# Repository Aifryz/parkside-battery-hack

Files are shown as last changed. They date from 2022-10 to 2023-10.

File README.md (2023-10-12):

# parkside-battery-hack
Hack which allow for the PLG 20 A1 charger to charge old style parkside 21V batteries (and possibly others)
### Status update: Battery died roughly 4 months after this change

## TLDR: Use Arduino Nano to fake the impulses sent by battery to enable the charger to work. See code for more info.
# The story
Some time ago a friend asked me if I could fix his parkside drill charger. Obviously I couldn't refuse, I love fixing stuff even when it makes little economic sense.

After taking a quick peek at the internals, it was obvious that it wouldn't be an easy job.
What I assumed were current sense/limiting resistors were completely vaporized. Main switching transistor was shorted, and I had little trust in the primary side switching ic. especially when I had no part number nor datasheet for it.
Replacement chargers were not available since it's an old design, but more modern chargers were available cheaply. We thought that maybe we could just simply replace the internals?

It doesn't look half bad, it seems like the battery is just being connected through MOSFET switch. The third pin marked as "ID" is probably used to check if the battery is inserted.
Maybe it would work if I connected the battery directly?

It didn't work. This charger have some self diagnostics which sense that the output is shorted/overloaded and disconnects the battery terminals from voltage output. In this case it was completely disabling the primary side switching IC, since the output voltage kept falling to approx 2V.

But how? Obviously we have an optocoupler. Normally this optocoupler would work with TL431 reg to regulate output voltage, but circuit in this charger was more complicated.

Obviously, I did not have a schematic available, so some reverse engineering was needed.
First thing I like to do when REing a board is to find details about the largets IC. In this case it was a LGT8P22A.
But the research resulted in only finding someone who had the same problem as I did.
Even the search on Baidu which sometimes help when researching obscure chineese ICs resulted in me finding someone who tried to find more data about this part.

# Reverse engineering
This board is a very simple single sided board, so reverse enginnering it was relatively pleasant experience.
After maybe 2 hours to mark the connections and another 2 hours to redraw the schematics I had something I could work with.

Resistors and capacitors are easy, since values are already written on them.
With some other components, i could immediately decode what they were using standard smd code books.
Others were more tricky, such as the what I guess is the main switching IC, and some SOT23 parts.
Thanks to the schematics above I assumed that the SOT23 part had to be a TL431 clone. The only way to find out if it was was to measure voltage at X terminal.
Beautiful 2.5V confirmed my suspicions. This charger is alsmost identical to standard issue TL431 powered isolated SMPS.
The only interesting thing was this weird combination of 2 resistors and  1 capacitor connected between TL431  and LGT8P22A.
It had to be an output from LGT8P22A since if we assume that the path is high impedance we can see that we cannot get the nominal 21V at the output needed to charge the battery packs.

The only way that we could get 21v at battery terminals is when this branch would be tied to GND.
So this pin has to be some kind of output. Rather large R and C looks a lot like a low pass filter. Maybe it's simple PWM DAC?

Indeed it looks like one.
So the LGT8P22A part is obviously some kind of microcontroller used both to check if valid battery is connected and to regulate the output voltage. It's also used in the battery packs.
My first thought, as a primarily software dev was to try and readout the program memory, reverse enginner this protection disable it and reprogram. That quickly fell through after roughly 27 seconds of thinking:
- I did not have pinout
- I did not have the datasheet
- I did not know the architecture
- I did not know if it was a reprogrammable part (probably not)
But maybe there's easier way in?
As I said before, the battery pack is connected by 3 terminals: "+", "-" and ID
"+" and "-" are obvious, they are directly connected to the cells but the ID pin is intersting.
From what I found while doing research on this charger I found out that the battery communicates with charger using series of impulses. Let's attack that!
But there's a problem, I don't have the battery for this charger, only the older model.
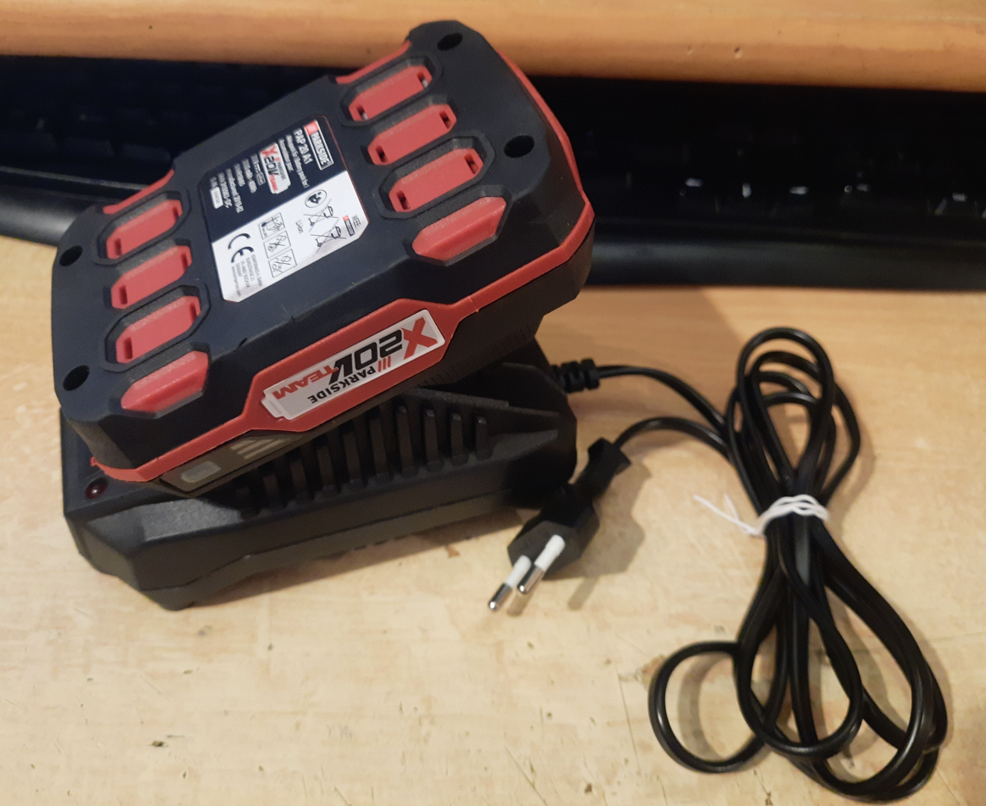
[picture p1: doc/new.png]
Image of a new charger and battery

So 120 PLN later I became an owner of a fresh battery and even fresher charger :)

After confirming that the charger internals were the same, I scoped the ID pin hoping that the protocol would be a simple. Luckily a simple repeating pulse pattern apeared.
Sadly it wasn't UART so some more work was needed.

So if we were to falsely generate this ID signal we could possibly fake that battery is connected. So let's do this.
Originally I wanted to use a STM32 since I work with them at work and know the timer peripheral well but I rejected that since i needed 5V signaling and a perfectly good Arduino Nano was laying around doing nothing in my parts drawers.

Since the timebase is so slow (bit time of 1msec) I didn't bother with hardware pulse generation. Everything was written using single timer and basic GPIO toggling in ISR.
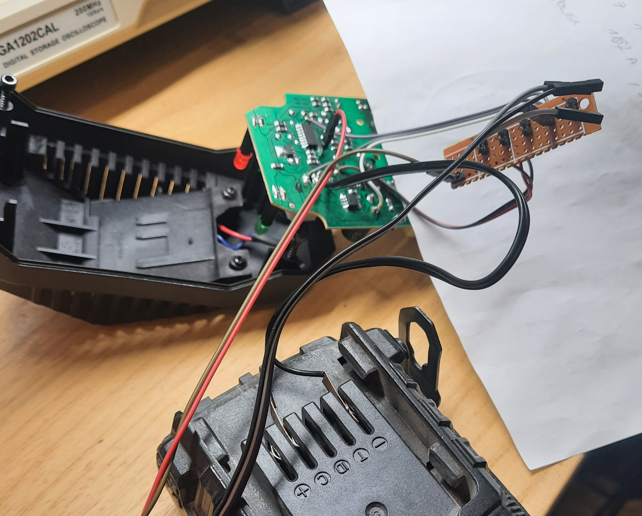
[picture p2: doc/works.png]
Red LED means it works


It works, just need to pack it nicely, or atleas safely.
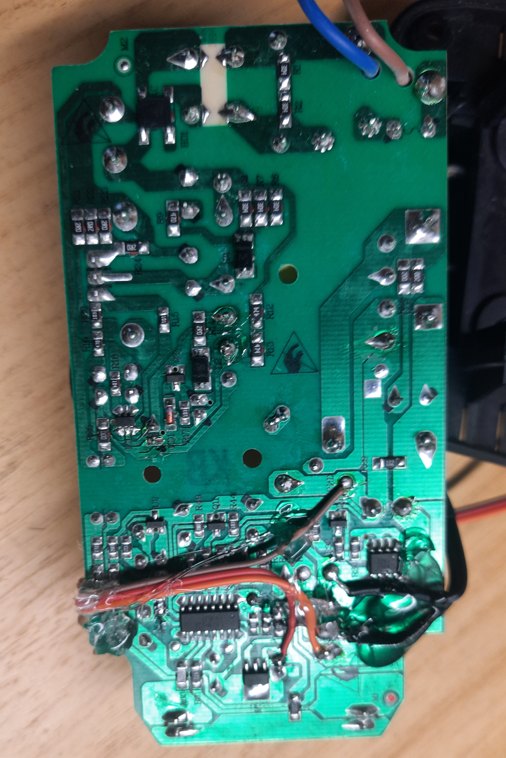
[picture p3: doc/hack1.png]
Image of charger covered in hot glue

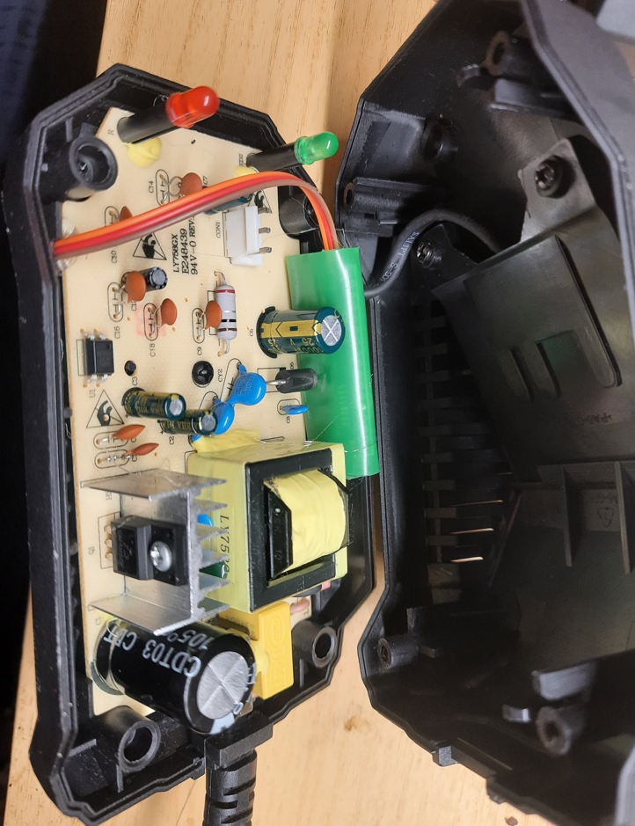
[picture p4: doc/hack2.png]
Image of charger with arduino nano glued to the side of it

Sadly the old and new case differ so much that I couldn't easily fit everything inside a single one so this monstrocity was born.

# Conclusion
TBH if this wolud be my battery I wouldn't bother with any of that. I could charge this battery using current limited power supply, which worked flawlessly. But since it was done for a friend who doesn't have a lab PSU it had to be done this way.

Possibly, this hack could be used to charge other types of batteries. I only replicated the ID signal, but this charger is supposedly compatible with other parkside batteries, this signal was measured using a PAP 20 A1 battery. If someone has access to other batteries (especially the larger PAP 20 B3 4Ah pack) I would be interested to see how the ID signal changes. Is the charging current dependent on it? Is it the same for every other device? Again if you could measure it I would be interested in it.

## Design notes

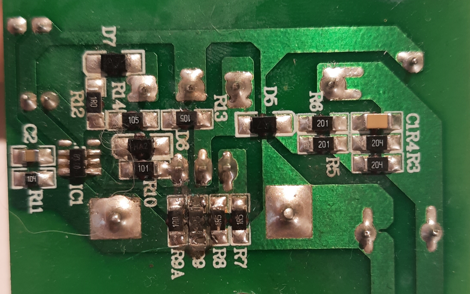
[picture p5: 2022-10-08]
doc/gone.png

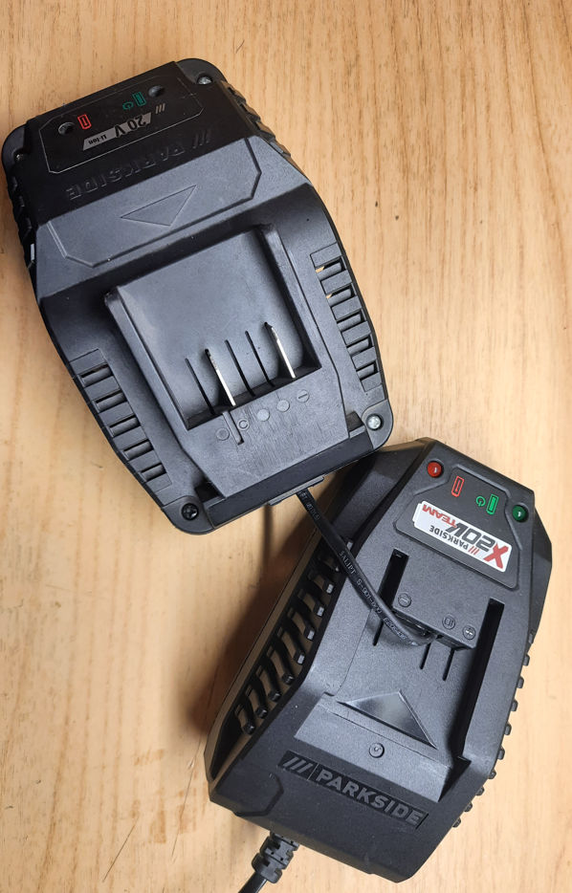
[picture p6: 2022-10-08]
doc/monster.png

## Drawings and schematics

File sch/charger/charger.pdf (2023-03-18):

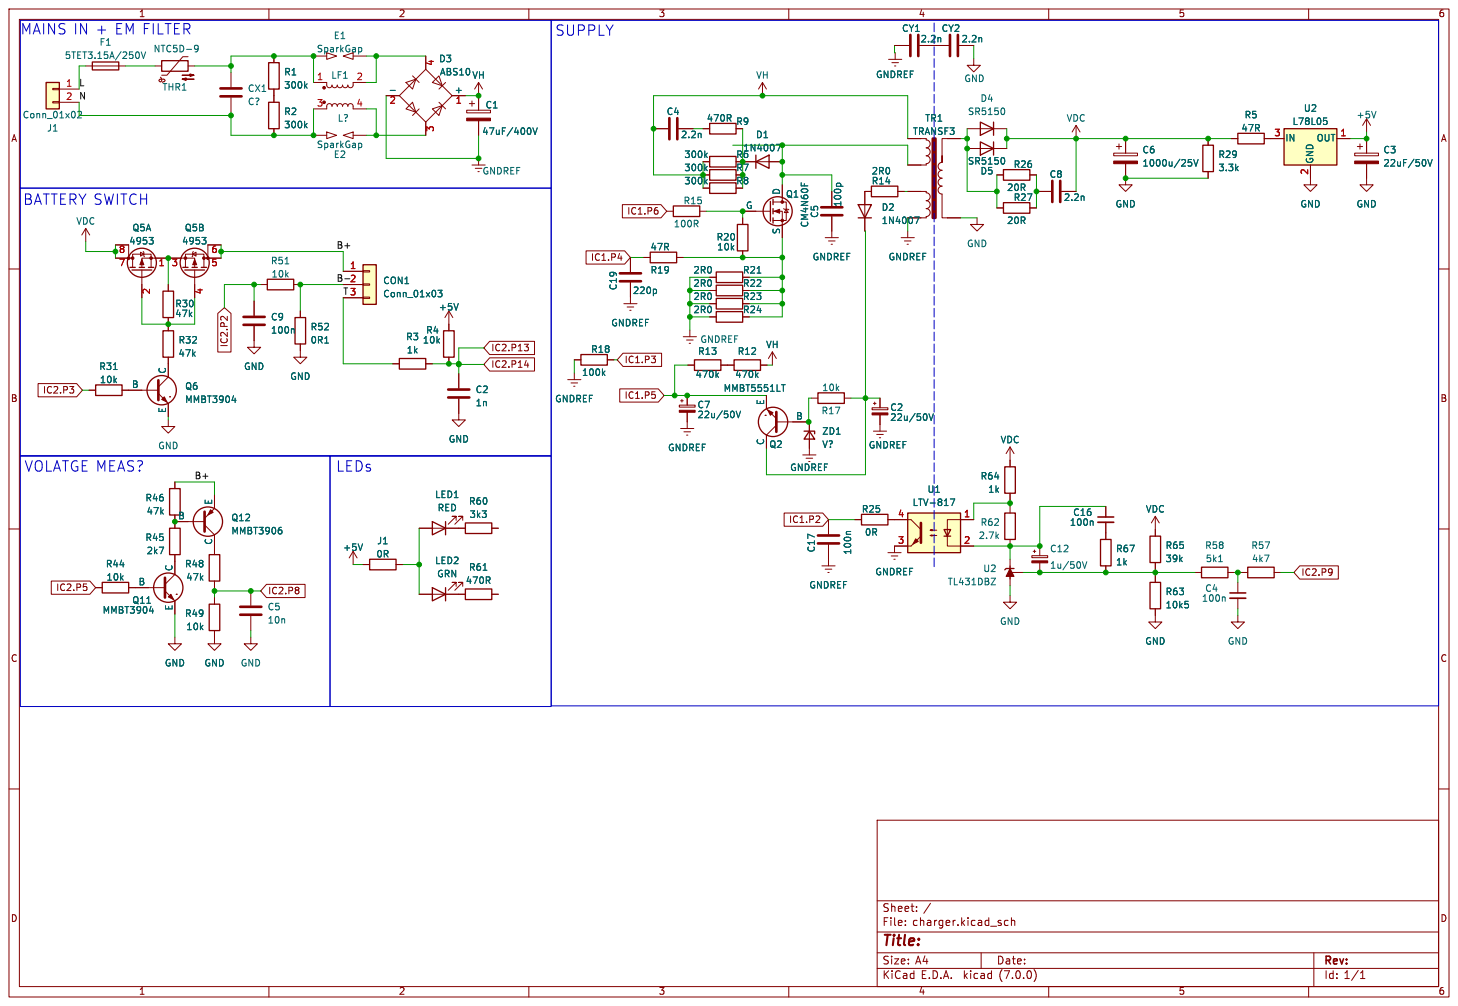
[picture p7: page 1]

B+B-T B+ MAINS IN + EM FILTER

Id: 1/1 Title: File: charger.kicad_sch Sheet: /

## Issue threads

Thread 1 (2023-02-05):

Witaj

Dreed420, 2023-02-05:
Widzę że ogarnąłeś temat ładowarki - ja mam problem z baterią, wymieniłem koledze ogniwa na większe - bateria podziałała dwa dni i po podłączeniu do ładowarki mruga czerwona dioda (sprawdziłem ogniwa są o równym napięciu) - inne baterie ładują się prawidłowo.
Czy mógłbym Cie prosić o soft do baterii którym mógłbym oszukać ładowarkę?
Nie chciałbym przerabiać ładowarki dla jednej baterii a sama elektronikę ciężko znaleźć - a widząc że masz wszystko rozgryziona myślę że to nie będzie problem dla Ciebie :))

Z góry dziękuje i czekam na odpowiedź

Dreed420, 2023-02-06:
Ładowarka to PLG 20 B1
Bateria PAP 20 A1

Szukam softu czym mógłbym zemulować sygnał ID bo padł układ LGT8P22A którego nie da się nigdzie zakupić

Aifryz, 2023-02-08:
Wszystko rozgryzione to dużo za dużo powiedziane :)
Teoretycznie ten program na arduino powinien spowodować że ładowarka rzeczywiście poda napięcie na baterie.
Ale wydaje mi się że układ LGT8P22A jest też częścią BMSa w samym akumulatorze i wyłącza ładowanie po stronie baterii. Nie wiem czy dałbym radę coś tu zdziałać bez analizowania całego akumulatora.

Próbowałeś ładować tą baterię zasilaczem z regulowanym limitem prądu wyjściowego?

Dreed420, 2023-02-09:
tak zasilaczem serwisowym ładuje się bez problemu, poszedłem nawet dalej -
wgrałem twój program do arduino, pod pin D9 podpiąłem pin ID w baterii oraz mase do GND i ładowarka ruszyła - lecz nie kończy ładowania.
Nie umieściłeś żadnego pinout'u więc też trochę idę po omacku ;)

Aifryz, 2023-02-13:
Racja, nie wrzuciłem jeszcze schematów, ale zgadłeś z tym pinem D9 pod pin ID.

Co do samego kończenia ładowania - w moim przypadku też właściwie nie było dobrej detekcji końca ładowania. jak się naładowała to zaczęły dwie diody razem migać (wg. instrukcji - błąd baterii).  Nigdy nie miałem potrzeby aby sprawdzić jak wygląda komunikacja na końcu ładowania, więc tego nie robiłem.

Być może w tym tygodniu, albo w weekend będę miał chwilę czasu to postaram się wymyślić jakiś sposób na zmierzenie tego.
Z takim zwykłym mierzeniem przy użyciu analizatora może być problem bo trzeba wychwycić moment kiedy bateria przestaje się ładować, a to może być po paru godzinach.

Discorda mam, ale używam go trochę jak maila, wyłączone powiadomienia i sprawdzam raz na dzień.

Dreed420, 2023-02-13:
>Z takim zwykłym mierzeniem przy użyciu analizatora może być problem bo trzeba wychwycić moment kiedy bateria przestaje się ładować, a to może być po paru godzinach.

a włożenie naładowanej baterii i sprawdzenie jak wygląda 'finisz' ? :)

Aifryz, 2023-02-28:
Nareszcie miałem okazję zobaczyć jak wyglądają sygnały podczas całego ładowania. Sygnał ID zmienia się kilkaset msek przed końcem ładowania. Czyli wygląda jakby to rzeczywiście bateria decydowała kiedy ma się odłączyć. Z tym nie uda mi się mi wiele zdziałać.

Jedyny pomysł jak to zrobić to byłoby mierzenie prądu który płynie przez rezystor pomiarowy na plytce i odcinanie sygnału jak prąd spadnie poniżej jakiegoś progu. Tylko to wymagałoby modyfikacji ładowarki.

Samo to, że ładowarka nie przestaję ładować może być spowodowane też jakimś małym zwarciem w bateri (kilkadziesiąt-kilkaset ohm). Wtedy rzeczywiście ładowarka ciągle by musiała podawać prąd.
Można to sprawdzić mierząc prąd płynący do baterii.

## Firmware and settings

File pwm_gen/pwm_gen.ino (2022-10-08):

// OC1A, PB1, pin9
volatile uint16_t counter;
const uint8_t pattern[5] = {0x00, 0x88, 0x33, 0x44, 0x77};
volatile int cnt;
void setup() {
  // put your setup code here, to run once:
  //pinMode (9, INPUT) ;
  //digitalWrite (9, LOW) ;
  digitalWrite (9, HIGH) ;
   pinMode (9, OUTPUT) ;  
  Serial.begin(9600);
  //We delay for some time
  //WARNING, old bootloader is too slow for this application, you need to flash new faster bootloader onto the Arduino Nano for this code to work
  delay(585);
  delay(12);
  // Setup Timer 1 for interrupt every 1 msec
  TCCR1A = 0;
  TCCR1B = (1<<CS11) | (1<<WGM12);
  uint16_t time = 1999;
  OCR1AH = time>>8;
  OCR1AL = time&0xFF;
  TIMSK1 |= (1<<OCIE1A);
  Serial.println("start");
  sei();

}

ISR(TIMER1_COMPA_vect){
  cnt += 1;
  if(counter <40)
  {
    uint32_t idx = counter/8;
    uint32_t sub = counter%8;     
    uint8_t val = pattern[idx];
    uint8_t bval = val&(1<<(7-sub));
    digitalWrite(9, bval);
  }

  counter+= 1;

  if(counter >= 40+205-2)
  {
    counter = 0;
  }
  
}
void loop() {
  // put your main code here, to run repeatedly:
  delay(1);
  Serial.println(cnt); // Print cnt for debugging
}

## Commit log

2023-03-18 Add initial charger schematic
    [charger.kicad_pcb, charger.kicad_sch]
2023-03-18 Cleanup schematic
    [charger.kicad_sch]
